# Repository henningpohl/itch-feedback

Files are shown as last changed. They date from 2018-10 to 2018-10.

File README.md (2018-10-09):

# Itch Feedback
This is a repository for content related to the [*ElectricItch: Skin Irritation as a Feedback Modality*](https://doi.org/10.1145/3242587.3242647) paper, published at [UIST 2018](https://uist.acm.org/uist2018/).

## Contents
At this point, this repository contains:
 - The paper itself
 - The schematics and board layout for [Autodesk EAGLE](https://www.autodesk.com/products/eagle/overview)
 - Firmware code for the [Adafruit Feather M0 Bluefruit LE](https://www.adafruit.com/product/2995), as a [Platform.IO](http://platformio.org/platformio-ide) project (likely works with other boards and IDEs)

## License
See the LICENSE file. Basically all our work is released under the MIT License --- do whatever you want with it. Note though that the firmware uses the [Timer5 library](https://github.com/michael71/Timer5), which is licensed under the GNU LGPL.

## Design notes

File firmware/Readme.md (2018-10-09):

# Building the firmware

To directly compile and deploy this project you'll need the [PlatformIO IDE](https://platformio.org/platformio-ide). We only used this with the *Visual Studio Code* version, but it should also work with the *Atom* version. 

Open this folder as a workspace and then use the IDE's *build* and *upload* tools to deploy (you should be able to find them in the lower command bar). 

If you are using another IDE (such as the Arduino one), the code should still work in that case. In case of the Arduino IDE, moving the code from *main.cpp* to the corresponding *PROJECT_NAME.ino* file likely works.

We do not guarantee anything with regards to this code. We have only used it with the Adafruit Feather M0 Bluetooth, but it should also work on other boards (with the appropriate changes).

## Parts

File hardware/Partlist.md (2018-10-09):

# Components used to build itch boards v4.1

**Note:** We built many versions of the itch stimulator and this part list does not cover all those. We did not test version 4.1 of the itch stimulator (the one we are releasing) and do not guarantee that the listed components will work well. Apply common sense when building your own and double check the components. We provide no warranty or guarantees with this release.

| Component | Amount | Mfg. Part No | Mouser Link |
|---|---|---|---|
| 261k Ohm Resistor | 1 | 667-ERA-6AEB2613V | http://www.mouser.dk/ProductDetail/Panasonic/ERA-6AEB2613V/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 |
| 267k Ohm Resistor | 1 | 667-ERA-6AEB2673V | http://www.mouser.dk/ProductDetail/Panasonic/ERA-6AEB2673V/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 |
| 10k Ohm Resistor | many | 603-RT0805DRD0710KL | http://www.mouser.dk/ProductDetail/Yageo/RT0805DRD0710KL/?qs=sGAEpiMZZMu61qfTUdNhGxEjuuBLd0B4jxMgsjb902w%3d |
| 100k Ohm Resistor | 2 | 603-RT0805FRE07100KL | http://www.mouser.dk/ProductDetail/Yageo/RT0805FRE07100KL/?qs=sGAEpiMZZMu61qfTUdNhGxEjuuBLd0B4mFnwhs6X5Kw%3d |
| 1M Ohm Resistor | 2 | 603-RT0805FRE071ML | http://www.mouser.dk/ProductDetail/Yageo/RT0805FRE071ML/?qs=sGAEpiMZZMu61qfTUdNhG17bj55vCpcB%252bW0r8W2Omo8%3d |
| 1uF Capacitor | 1 | 963-UMK212B7105KG-T | http://www.mouser.dk/ProductDetail/Taiyo-Yuden/UMK212B7105KG-T/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 |
| 4.7uF Capacitor | 1 | 581-08055D475KAT2A | http://www.mouser.dk/ProductDetail/AVX/08055D475KAT2A/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 |
| 22nF Capacitor | 1 | 710-885012207094 | http://www.mouser.dk/ProductDetail/Wurth-Electronics/885012207094/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 |
| 10uF Capacitor | 1 | JMK212ABJ106KD | http://www.mouser.dk/ProductDetail/Taiyo-Yuden/JMK212ABJ106KD-T/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 |
| ~~10uH Indictor~~ | ~~1~~ | ~~LBR2012T100K~~ | ~~http://www.mouser.dk/ProductDetail/Taiyo-Yuden/LBR2012T100K/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 |
| 10uH Inductor | 1 | LQH32PN100MN0 | http://www.mouser.dk/ProductDetail/Murata/LQH32PN100MN0L/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 |
| Shottky Diode | 1 | 833-SK14-LTP | http://www.mouser.dk/ProductDetail/Micro-Commercial-Components-MCC/SK14-LTP/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 |
| DMHC4035LSD H-Bridge | 1 | DMHC4035LSD-13 | http://www.mouser.dk/ProductDetail/Diodes-Incorporated/DMHC4035LSD-13/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 |
| N-Channel MOSFET | 2 | NTR5103NT1G | http://www.mouser.dk/ProductDetail/ON-Semiconductor/NTR5103NT1G/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 |
| ~~MCP41HV digital potentiometer (36V)~~ | ~~1~~ | ~~MCP45HV51-103E/ST~~ | ~~http://www.mouser.dk/ProductDetail/Microchip-Technology/MCP45HV51-103E-ST/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 |
| MCP41HV digital potentiometer (36V) | 1 | MCP41HV51-502E/ST | http://www.mouser.dk/ProductDetail/Microchip-Technology/MCP41HV51-502E-ST/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 |
| PSSI2021SAY,115 current source (75V) | 1 | PSSI2021SAY,115 | http://www.mouser.dk/ProductDetail/Nexperia/PSSI2021SAY115/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 |
| MIC2619 Boost Converter (35V)	| 1 | MIC2619YD6-TR | http://www.mouser.dk/ProductDetail/Microchip-Technology-Micrel/MIC2619YD6-TR/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 |
| Adafruit Feather M0 Bluetooth LE | 1 | 2995 | http://www.mouser.dk/Search/ProductDetail.aspx?R=2995virtualkey54850000virtualkey485-2995 |
| Female Headers for Adafruit Feather | 1 | 2886 | http://www.mouser.dk/ProductDetail/Adafruit/2886/?qs=sGAEpiMZZMvt1VFuCspEMq3fKZ%252bMxqLgHF0CTCQqiVI%3d |
| Pin Header | some | 517-929834-01-32 | http://www.mouser.dk/ProductDetail/3M-Electronic-Solutions-Division/929834-01-32/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 |

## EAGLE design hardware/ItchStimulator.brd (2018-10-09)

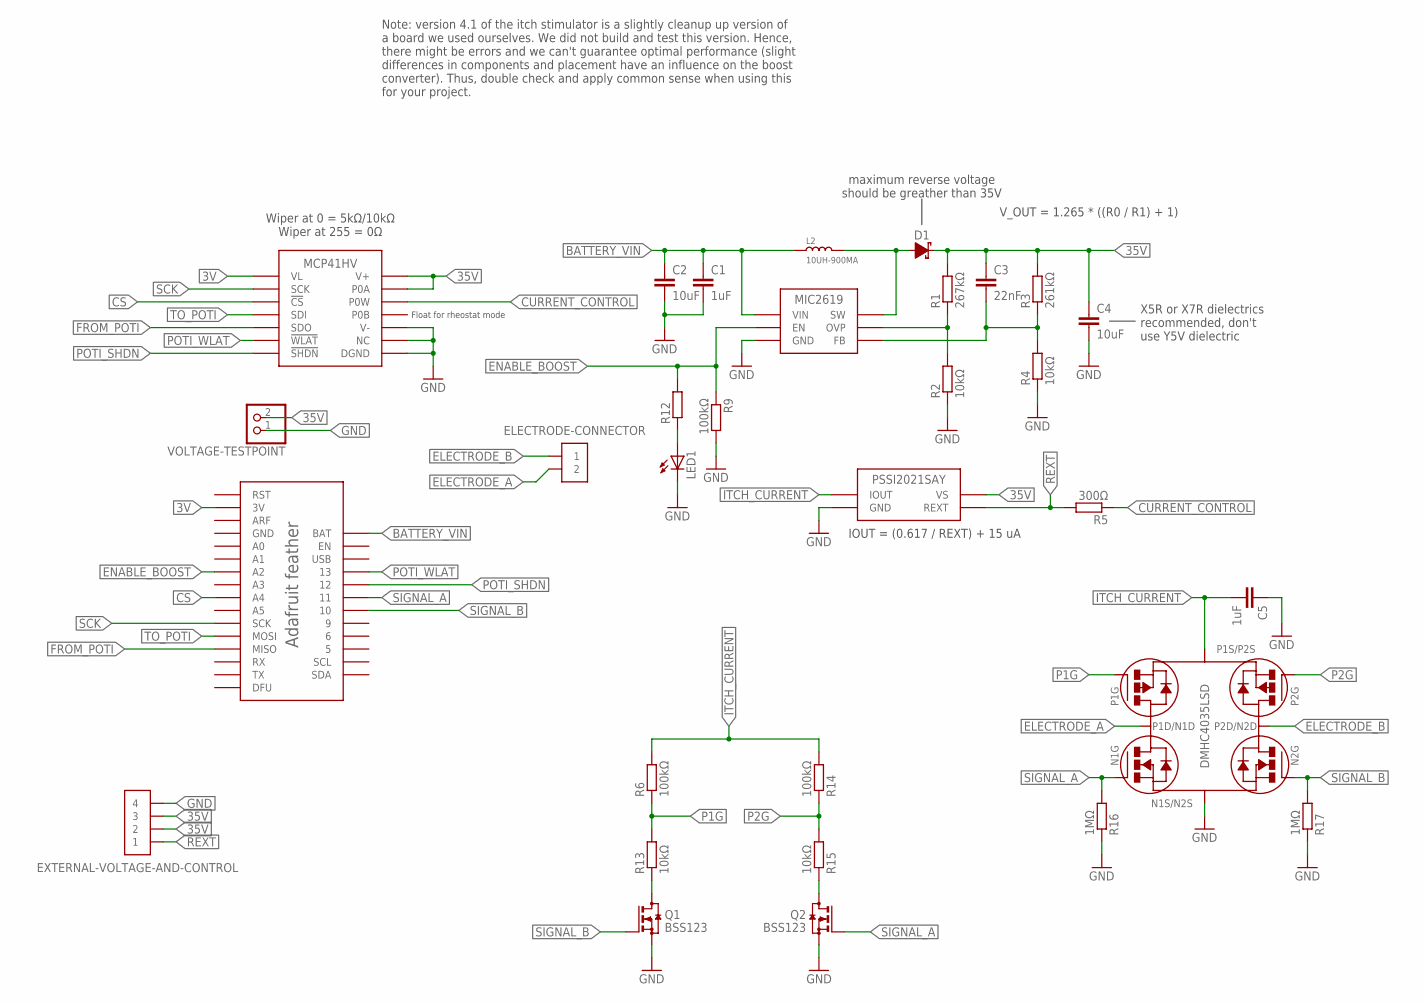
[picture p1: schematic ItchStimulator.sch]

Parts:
C1, C5: 1uF; C0805K
C2, C4: 10uF; C0805K
C3: 22nF; C0805K
D1: DIODE-SCHOTTKY; DO-214AA
ELECTRODE-CONNECTOR: 2-PIN_HEADER; SAMTEC-TSM-102-01-X-SH
EXTERNAL-VOLTAGE-AND-CONTROL: 4-PIN_HEADER; SAMTEC-TSM-104-01-X-SH
L2: 10UH-900MA; L1210
LED1: LEDSML0805; SML0805
MCP41HV: MCP41HV; TSSOP-14
MIC2619: MIC2619; TSOT-23-6
PSSI2021SAY: PSSI2021SAY; SOT-353
Q1, Q2: BSS123; SOT23
R1: 267kΩ; R0805
R2, R4, R13, R15: 10kΩ; R0805
R3: 261kΩ; R0805
R5: 300Ω; R0805
R6, R9, R14: 100kΩ; R0805
R12: R-EU_R0805; R0805
R16, R17: 1MΩ; R0805
U$1: ADAFRUIT_FEATHER_M0_BLUETOOTH
U$2: DMHC4035LSD; SOIC-8
VOLTAGE-TESTPOINT: PINHD-1X2; 1X02

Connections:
3V: MCP41HV.P$1 (VL), U$1.P$15 (3V)
35V: C3.1, C4.1, D1.CATHODE, EXTERNAL-VOLTAGE-AND-CONTROL.P$2 (2), EXTERNAL-VOLTAGE-AND-CONTROL.P$3 (3), MCP41HV.P$13 (P0A), MCP41HV.P$14 (V+), PSSI2021SAY.P$5 (VS), R1.2, R3.2, VOLTAGE-TESTPOINT.2
BATTERY_VIN: C1.1, C2.1, L2.1, MIC2619.P$6 (VIN), U$1.P$17 (BAT)
CS: MCP41HV.P$3 (!CS), U$1.P$8 (A4)
CURRENT_CONTROL: MCP41HV.P$12 (P0W), R5.1
ELECTRODE_A: ELECTRODE-CONNECTOR.P$2 (2), U$2.P$2 (P1D/N1D)
ELECTRODE_B: ELECTRODE-CONNECTOR.P$1 (1), U$2.P$6 (P2D/N2D)
ENABLE_BOOST: MIC2619.P$4 (EN), R9.1, R12.2, U$1.P$10 (A2)
FROM_POTI: MCP41HV.P$5 (SDO), U$1.P$4 (MISO)
GND: C1.2, C2.2, C4.2, C5.1, EXTERNAL-VOLTAGE-AND-CONTROL.P$4 (4), LED1.C, MCP41HV.P$8 (DGND), MCP41HV.P$9 (NC), MCP41HV.P$10 (V-), MIC2619.P$2 (GND), PSSI2021SAY.P$3 (GND), Q1.2 (S), Q2.2 (S), R2.1, R4.1, R9.2, R16.1, R17.1, U$1.P$13 (GND), U$2.P$3 (N1S/N2S), VOLTAGE-TESTPOINT.1
ITCH_CURRENT: C5.2, PSSI2021SAY.P$2 (IOUT), R6.2, R14.2, U$2.P$7 (P1S/P2S)
unnamed: D1.ANODE, L2.2, MIC2619.P$1 (SW)
unnamed: C3.2, MIC2619.P$3 (FB), R3.1, R4.2
unnamed: LED1.A, R12.1
unnamed: MIC2619.P$5 (OVP), R1.1, R2.2
unnamed: Q1.3 (D), R13.1
unnamed: Q2.3 (D), R15.1
P1G: R6.1, R13.2, U$2.P$8 (P1G)
P2G: R14.1, R15.2, U$2.P$5 (P2G)
POTI_SHDN: MCP41HV.P$7 (!SHDN), U$1.P$21 (12)
POTI_WLAT: MCP41HV.P$6 (!WLAT), U$1.P$20 (13)
REXT: EXTERNAL-VOLTAGE-AND-CONTROL.P$1 (1), PSSI2021SAY.P$4 (REXT), R5.2
SCK: MCP41HV.P$2 (SCK), U$1.P$6 (SCK)
SIGNAL_A: Q2.1 (G), R16.2, U$1.P$22 (11), U$2.P$1 (N1G)
SIGNAL_B: Q1.1 (G), R17.2, U$1.P$23 (10), U$2.P$4 (N2G)
TO_POTI: MCP41HV.P$4 (SDI), U$1.P$5 (MOSI)
USB: U$1.P$19 (USB)

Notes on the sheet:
X5R or X7R dielectrics recommended, don't use Y5V dielectric
maximum reverse voltage should be greather than 35V
V_OUT = 1.265 * ((R0 / R1) + 1)
IOUT = (0.617 / REXT) + 15 uA
Float for rheostat mode
Wiper at 0 = 5kΩ/10kΩ Wiper at 255 = 0Ω
Note: version 4.1 of the itch stimulator is a slightly cleanup up version of a board we used ourselves. We did not build and test this version. Hence, there might be errors and we can't guarantee optimal performance (slight differences in components and placement have an influence on the boost conv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

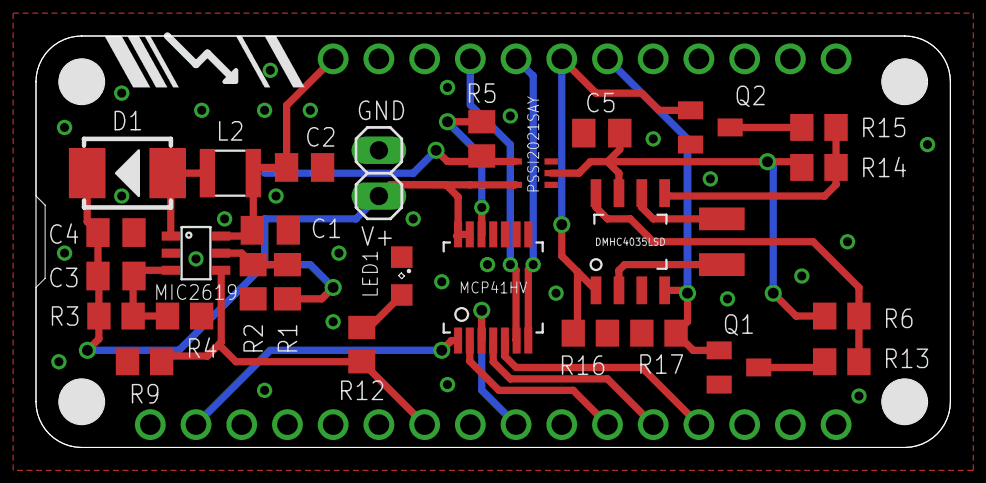
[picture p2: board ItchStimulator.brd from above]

Board: 2 copper layers, 50.8 x 22.9 mm, 31 parts (1 on the bottom side), 26 nets.

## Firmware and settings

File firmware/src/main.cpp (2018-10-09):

#include <Arduino.h>

#define BOARD_VARIANT 1
#if BOARD_VARIANT == 1
  #define BOARD_NAME "Left Board"
  #define BOARD_SPECS "5000 dynamic,0 fixed,255 steps"
#elif BOARD_VARIANT == 2
  #define BOARD_NAME "Right Board"
  #define BOARD_SPECS "5000 dynamic,0 fixed,255 steps"
#else
  #error Invalid board variant
#endif

#define INCLUDE_TESTS 1

#include "SignalController.h"
#include "CommandParser.h"

void onEnableChange(bool enable) {
  if(enable) {
    turnOnSignal();
    //digitalWrite(LED_BUILTIN, HIGH);
  } else {
    turnOffSignal();
    //digitalWrite(LED_BUILTIN, LOW);
  }
}

void setup() {
  // Uncomment lines below to wait for IDE connection on start
  //while (!Serial);
  //delay(500);
  Serial.begin(115200);
  Serial.println("Connected: send '?' for help");

  //pinMode(LED_BUILTIN, OUTPUT);
  //digitalWrite(LED_BUILTIN, LOW);
  setupSignal();
}



void loop() {
  while(Serial.available() > 0) {
    processByte(Serial.read());
  }

#if INCLUDE_TESTS
  if(loopTestFunction) {
    loopTestFunction();
  }
#endif
  delay(100);
}

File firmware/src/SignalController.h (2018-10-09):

#pragma once

#include "Timer5.h"
#include "MCP41HV.h"
#include "CommandParser.h"

const int SIGNAL_A = 11;
const int SIGNAL_B = 10;
const int BOOST_ENABLE = A2;

const int POTI_CS = A4;
const int POTI_WLAT = 13;
const int POTI_SHDN = 12;
MCP41HV poti(POTI_CS);

bool isTurnedOn = false;

#if INCLUDE_TESTS
  typedef void (* LoopFunction)();
  LoopFunction loopTestFunction = nullptr;
#endif


const uint16_t TIMER_TICKS = 32768;
const double MICROSECONDS_TO_TICKS = TIMER_TICKS / 1000000.0;
uint16_t signalToggle = 655; // 50Hz
uint16_t pulseToggle = 65; // 2ms pulse
uint16_t curTimerState = 0;

void Timer5_IRQ() {
  if(!isTurnedOn) {
    return;
  }

  if(curTimerState == 0) {
    digitalWrite(SIGNAL_A, HIGH);
  } else if(curTimerState == pulseToggle) {
    digitalWrite(SIGNAL_A, LOW);
  } else if(curTimerState == pulseToggle + 20) {
    digitalWrite(SIGNAL_B, HIGH);
  } else if(curTimerState == (2 * pulseToggle + 20)) {
    digitalWrite(SIGNAL_B, LOW);
  }
  
  curTimerState = (curTimerState + 1) % (signalToggle + 1);
}

void onParameterChange(SignalParameters & params) {
  poti.writeWiperValue(params.amplitude);
  signalToggle = TIMER_TICKS / params.frequency;
  pulseToggle = params.pulseWidth * MICROSECONDS_TO_TICKS; 
  curTimerState = 0;
}

void setupSignal() {
  pinMode(POTI_WLAT, OUTPUT);
  pinMode(POTI_SHDN, OUTPUT);
  pinMode(SIGNAL_A, OUTPUT);
  pinMode(SIGNAL_B, OUTPUT);
  pinMode(BOOST_ENABLE, OUTPUT);

  poti.setup();
  SPI.begin();

  MyTimer5.begin(1); // run at full 32768 Hz
  MyTimer5.attachInterrupt(Timer5_IRQ);

  digitalWrite(BOOST_ENABLE, LOW);
  digitalWrite(POTI_WLAT, LOW); // Don't delay wiper value updates
  digitalWrite(POTI_SHDN, LOW); // Shut down initially
  digitalWrite(SIGNAL_A, LOW);
  digitalWrite(SIGNAL_B, LOW);
}

void turnOnSignal() {
#if INCLUDE_TESTS
  loopTestFunction = nullptr;
#endif

  isTurnedOn = true;
  digitalWrite(BOOST_ENABLE, HIGH);
  digitalWrite(POTI_SHDN, HIGH);
  MyTimer5.begin(1); // run at full 32768 Hz
  MyTimer5.start();
}

void turnOffSignal() {
#if INCLUDE_TESTS
  loopTestFunction = nullptr;
#endif

  isTurnedOn = false;
  digitalWrite(BOOST_ENABLE, LOW);
  digitalWrite(POTI_SHDN, LOW);
  MyTimer5.end();
}

#if INCLUDE_TESTS
void constantTestSignal(uint8_t strength) {
  isTurnedOn = false;
  MyTimer5.end();
  digitalWrite(BOOST_ENABLE, HIGH);
  digitalWrite(POTI_SHDN, HIGH);
  poti.writeWiperValue(strength);
  digitalWrite(SIGNAL_A, LOW);
  digitalWrite(SIGNAL_B, HIGH);

}

uint8_t rampTestState;
void rampLoopFunction() {
  poti.writeWiperValue(rampTestState);
  rampTestState--;
  digitalWrite(SIGNAL_A, LOW);
  digitalWrite(SIGNAL_B, HIGH);
  delayMicroseconds(2000);
  digitalWrite(SIGNAL_A, LOW);
  digitalWrite(SIGNAL_B, LOW);
}

void rampTestSignal() {
  isTurnedOn = false;
  MyTimer5.end();
  digitalWrite(BOOST_ENABLE, HIGH);
  digitalWrite(POTI_SHDN, HIGH);
  digitalWrite(SIGNAL_A, LOW);
  digitalWrite(SIGNAL_B, LOW);
  rampTestState = 255;
  poti.writeWiperValue(rampTestState);
  loopTestFunction = rampLoopFunction;
}

void testSignalOutput() {
  digitalWrite(POTI_SHDN, HIGH);
  poti.writeWiperValue(234); // should be 1.5mA -> 15V over the 10k resistor
  isTurnedOn = true;
  MyTimer5.begin(1); // run at full 32768 Hz
  MyTimer5.start();
}

void testSignalOutput2() {
  digitalWrite(POTI_SHDN, HIGH);
  poti.writeWiperValue(220);
  digitalWrite(SIGNAL_B, HIGH);
  delay(2000);
  digitalWrite(SIGNAL_B, LOW);
  delay(2000);
  digitalWrite(SIGNAL_A, HIGH);
  delay(2000);
  digitalWrite(SIGNAL_A, LOW);
  delay(2000);
}

void selectTestMode(uint32_t testMode) {
  switch(testMode) {
    case 0:
      constantTestSignal(255);
      break;
    case 1:
      constantTestSignal(200);
      break;
    case 2:
      constantTestSignal(150);
      break;
    case 3:
      rampTestSignal();
      break;
  }
}
#endif

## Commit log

2018-10-09 Camera ready version of the paper
2018-10-09 Itch stimulator board v4.1
    [ItchStimulator.brd, ItchStimulator.sch]
